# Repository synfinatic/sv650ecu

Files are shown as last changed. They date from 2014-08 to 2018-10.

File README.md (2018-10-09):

## Suzuki SV650 ECU Decoder

This is the Arduino code (for a [PJRC Teensy 2.0](http://www.pjrc.com/store/teensy.html)) 
and necessary CAD/schematic files for creating a PCB to creating your own 
2nd Generation SV650 ECU Decoder to replace the error lights & codes normally 
displayed by the stock dash unit.

This supports the following:

 * Oil pressure warning light
 * Neutral light
 * EFI warning light
 * Low fuel light *
 * Display the water temp from the the stock water temp sensor
 * Ability to decode EFI error codes from the SV650 ECU
 * TPS adjustment indicator **

[*] Note: Untested.

[**] Note: Normally the 4 digit LED display shows the water temp. 
To show the TPS indicator or ECU error codes, you’ll need to use a 
“Suzuki diagnostic tool” (aka a paperclip) to short two wires per the shop manual.

More information about this project is available 
[on my blog](http://synfin.net/sv650ecu "Suzuki SV650 ECU Decoder") and 
[on the wiki](https://github.com/synfinatic/sv650ecu/wiki).

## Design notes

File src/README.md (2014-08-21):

### Code

 * __sv650_reader__ This is the code which runs on the SV650 ECU Decoder and decodes the messages sent by the ECU.
 * __sv650_generator__ This is code written for an Arduino to emulate an SV650 ECU.
 * __sv650_temp__ This is code I wrote to walk through all the ADC temp values generated by the ECU to figure out how to map them to degrees fareinheit.
 * __SWSerial7800__ Customized version of NewSoftSerial library with support for 7800 baud

### Important

In order to build sv650_reader, sv650_generator and sv650_temp for Arduino, you will
need to import the 7800Serial library into the Arduino IDE.  To do so:
 1. Sketch -> Import Library -> Add Library
 2. Select the SWSerial7800 directory
 3. Click the "Choose" button

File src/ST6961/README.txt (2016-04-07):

This is the ST6961 library for the 4 digit LED display used
by sv650_reader, etc.  It's apparently now called the PT6961?

http://gtbtech.com/?p=528

Including it here for posterity sake.  To use it, be sure to
import this library into your Arduino IDE.

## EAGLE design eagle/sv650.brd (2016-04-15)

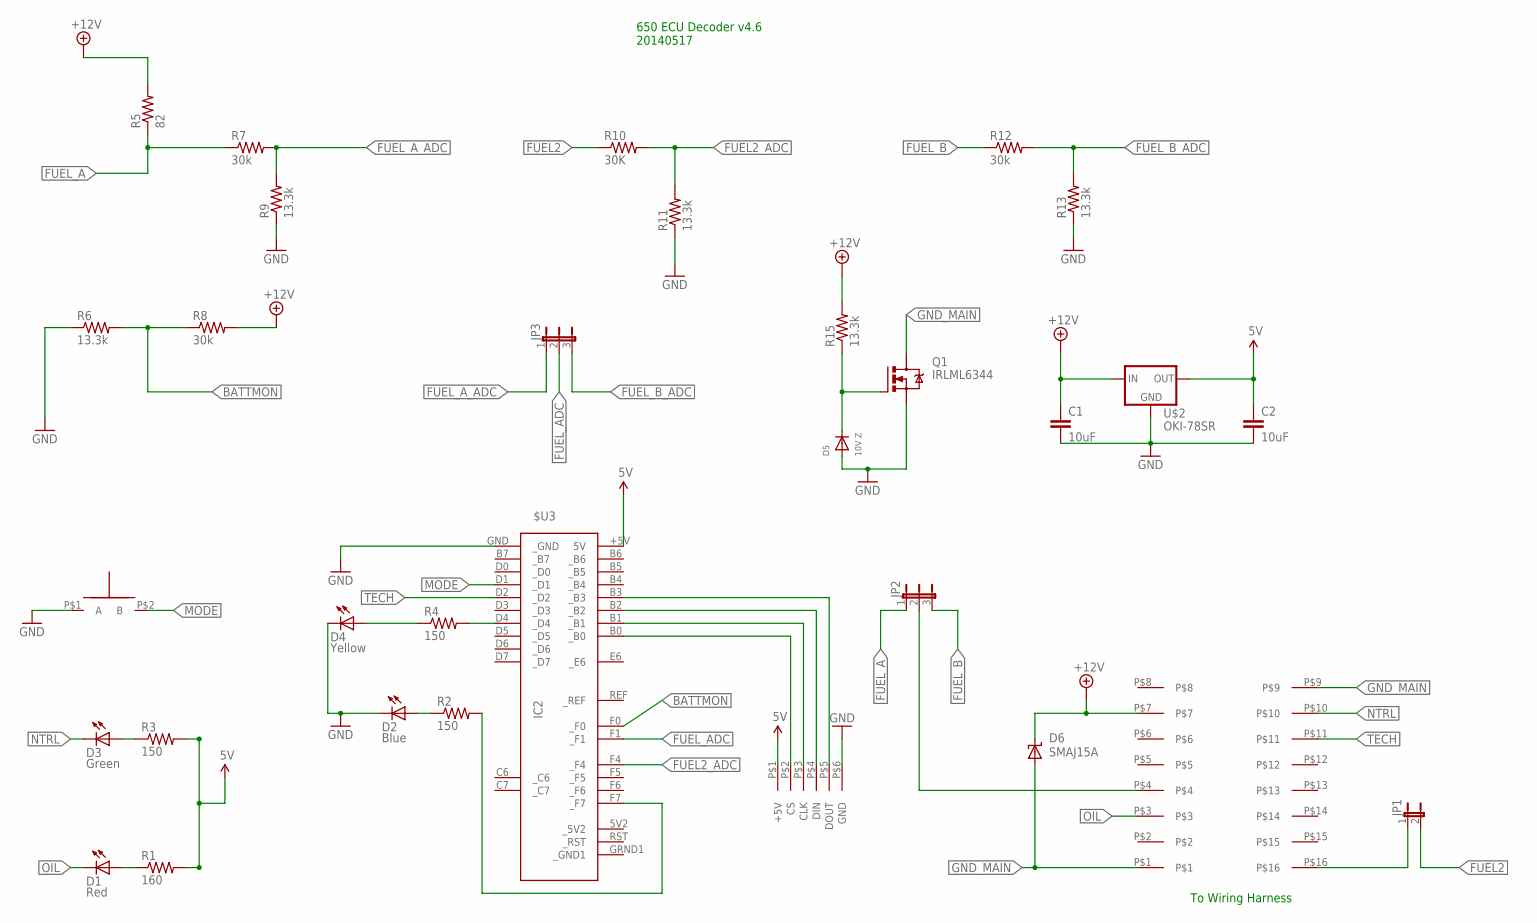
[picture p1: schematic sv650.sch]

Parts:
$U3: IC2; TEENSY
C1, C2: 10uF; C0805
D1: Red; LED10MM
D2: Blue; LED5MM
D3: Green; LED10MM
D4: Yellow; LED10MM
D5: 10V Z; SOD-123
D6: SMAJ15A; SMBG
JP1: JP1E; JP1
JP2, JP3: JP2E; JP2
Q1: IRLML6344; SOT23
R1: 160; M0805; MPN CRCW0805160RFKEA
R2, R3, R4: 150; M0805; MPN MCHP05W4F1500T5E
R5: 82; AXIAL-0.9
R6: 13.3k; M0805; MPN CRCW080510K0FKTA
R7, R12: 30k; M0805
R8: 30k; M0805; MPN CRCW080510K0FKTA
R9, R11, R13, R15: 13.3k; M0805
R10: 30K; M0805
U$1: OASIS-7-SEG-DISPLAY
U$2: OKI-78SR; OKI-78SR-H
U$3: TE-174975-2
U$10: R13-509A-05-BB/R13-509A-05-BR

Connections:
5V: $U3.+5V (5V), C2.1, R1.2, R3.2, U$1.P$1 (+5V), U$2.P$3 (OUT)
+12V: C1.1, D6.C, R5.P$2 (2), R8.2, R15.2, U$2.P$1 (IN), U$3.P$7
BATTMON: $U3.F0 (_F0), R6.2, R8.1
FUEL2: JP1.2, R10.1
FUEL2_ADC: $U3.F4 (_F4), R10.2, R11.2
FUEL_A: JP2.1, R5.P$1 (1), R7.1
FUEL_ADC: $U3.F1 (_F1), JP3.2
FUEL_A_ADC: JP3.1, R7.2, R9.2
FUEL_B: JP2.3, R12.1
FUEL_B_ADC: JP3.3, R12.2, R13.2
GND: $U3.GND (_GND), C1.2, C2.2, D2.K (C), D4.K (C), D5.A, Q1.2 (S), R6.1, R9.1, R11.1, R13.1, U$1.P$6 (GND), U$2.P$2 (GND), U$10.P$1 (A)
GND_MAIN: D6.A, Q1.3 (D), U$3.P$1, U$3.P$9
MODE: $U3.D1 (_D1), U$10.P$2 (B)
unnamed: $U3.B0 (_B0), U$1.P$2 (CS)
unnamed: $U3.B1 (_B1), U$1.P$3 (CLK)
unnamed: $U3.B2 (_B2), U$1.P$4 (DIN)
unnamed: $U3.B3 (_B3), U$1.P$5 (DOUT)
unnamed: D3.A, R3.1
unnamed: D2.A, R2.1
unnamed: D1.A, R1.1
unnamed: $U3.D4 (_D4), R4.2
unnamed: JP2.2, U$3.P$4
unnamed: JP1.1, U$3.P$16
unnamed: $U3.F7 (_F7), R2.2
unnamed: D5.C, Q1.1 (G), R15.1
NTRL: D3.K (C), U$3.P$10
OIL: D1.K (C), U$3.P$3
R2: D4.A, R4.1
TECH: $U3.D2 (_D2), U$3.P$11

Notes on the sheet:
To Wiring Harness
650 ECU Decoder v4.6 20140517

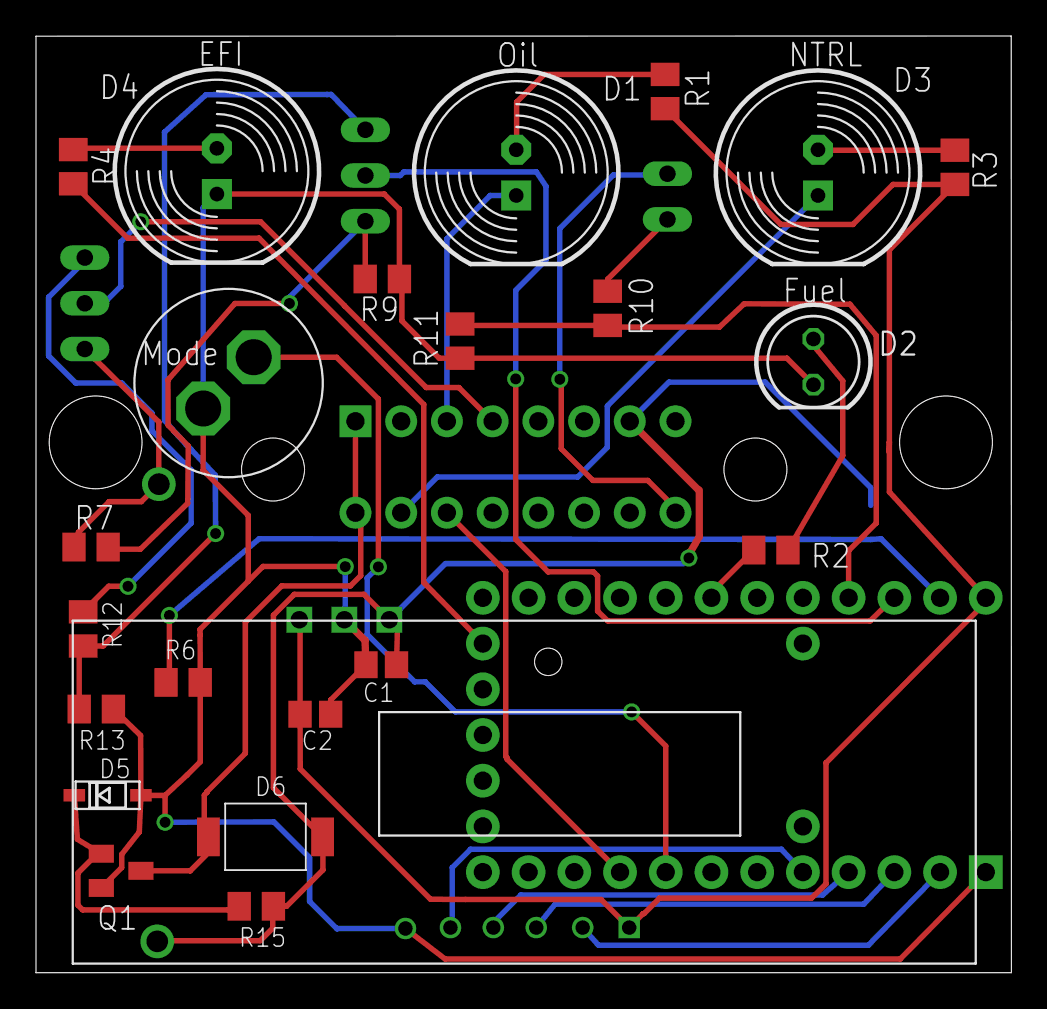
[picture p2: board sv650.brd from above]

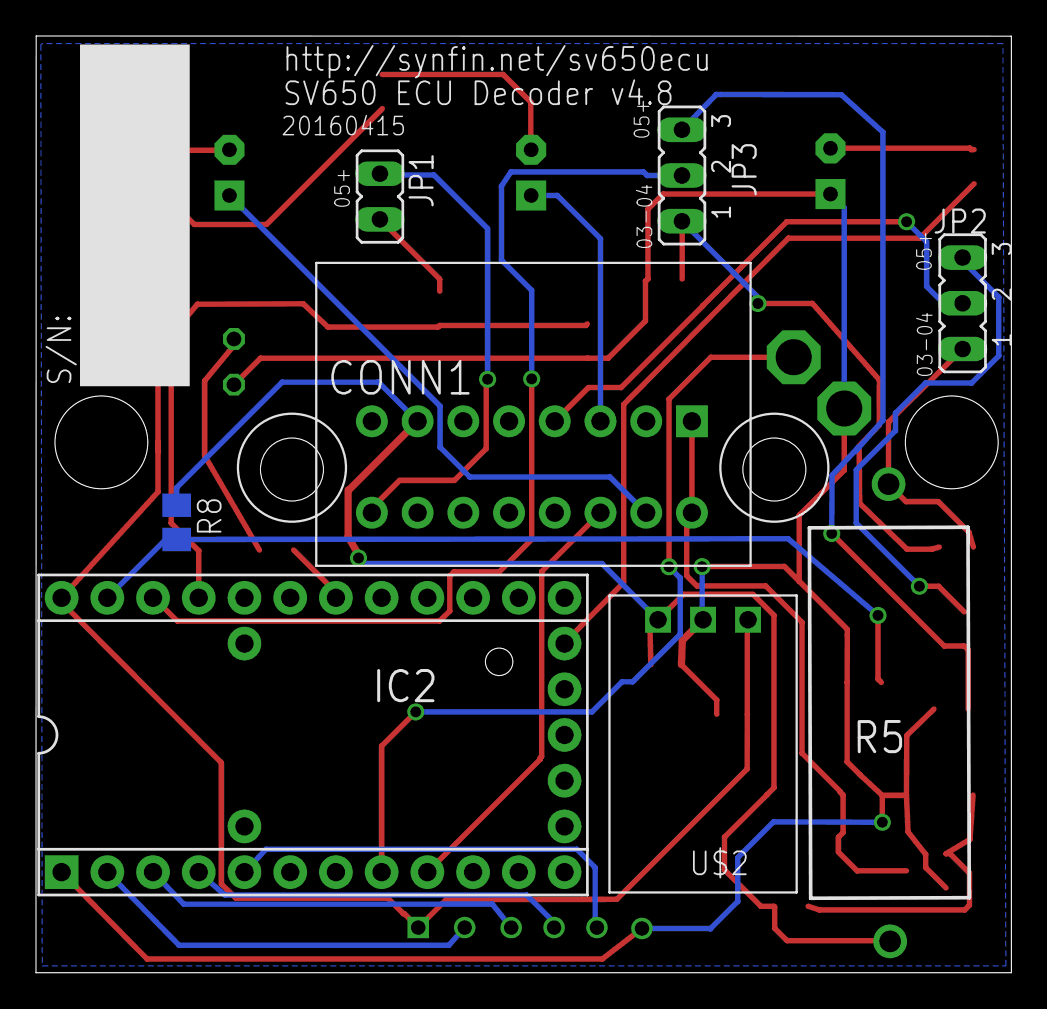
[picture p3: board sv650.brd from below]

Board: 2 copper layers, 54.2 x 52.0 mm, 32 parts (8 on the bottom side), 29 nets.

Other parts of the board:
U$5: STANDOFF

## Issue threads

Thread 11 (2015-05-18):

Add support for tach

synfinatic, 2015-05-18:
Needs to be on D0 (pin 5) for interrupt

synfinatic, 2015-05-18:
Ran out of interrupt pins.  (mode, oil, neutral, serial RX)

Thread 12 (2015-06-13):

Add support for K-line diagnostic

synfinatic, 2015-06-13:
Would be able to get gear position???  K-line is the serial debug port.

http://forum.arduino.cc/index.php?topic=236092.60

synfinatic, 2015-09-24:
http://www.aliexpress.com/item/SDS-For-Suzuki-Motorcycle-Diagnosis-System-Motorcycle-code-scanner/32356452298.html

k-line is also called SDS, and kwp2000.  appears to be a serial protocol
https://en.wikipedia.org/wiki/Keyword_Protocol_2000

synfinatic, 2015-10-06:
I ended up buying one of the Suzuki OBD/SDS diagnostic tools off of eBay for about $55.  Works great.  Looks like I can get air temp, water temp, gear position, rpm, TPS, etc all via the k-line.  You can even get what FI error codes have happened in the past.

To support the k-line, you need something like a ST L9637 to convert it to serial for a micro controller.

synfinatic, 2015-10-06:
ST L9637 spec sheet: [CD00000234.pdf](https://github.com/synfinatic/sv650ecu/files/8805/CD00000234.pdf)

synfinatic, 2015-10-11:
Manual circuit https://drive.google.com/file/d/0B1GutcZzC5ZvTzZsWFVzVWpVZnc/view

synfinatic, 2016-03-07:
Ended up buying an ELM327 based solution to see if that could read/decode the K-line on the SV.  Answer: No.

synfinatic, 2016-05-16:
Good references:
 * https://github.com/HerrRiebmann/KDS2Bluetooth
 * http://ecuhacking.activeboard.com/t56234221/kds-protocol/

synfinatic, 2016-05-18:
So looks like not only is Kawi's KWP2000 different from Suzuki, but we have differences between different models of Suzuki which explains the problem AiM has with my SV, but it working on the GSXR.

pathumha23, 2017-09-05:
Suzuki KWP2000 is different from conventional KWP2000 used in US and Europe systems
Use a scanner that supports JOBD protocol
Suzuki K line 1 and 2 is properitory and it is only communicated via JOBD capable tools
eg - Xtool PS 701JP , OBDMATE OM500

Or use an ELM 327 that supports KWP2000 (ISO 14230) (pin no. 7) and use OBD Driver or OBD Info San Android Apps as they support Suzuki K line 1 and 2

sirapol, 2025-04-07:
Are you still stuck it ?

MeY0u, 2025-07-09:
> Are you still stuck it ?

Got any knowledge about Suzuki marine sds?
Looking into reading df150

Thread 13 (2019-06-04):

Please release consolidated code

NoobDude2001, 2019-06-04:
Hello, I am attemtping to replicate this project. Would you mind posting a .ino file with the code for all the features together? I am new to Arduino and coding, and  I am struggling to get the syntax correct when putting the different features together.

Please and thank you!

Closed 2019-06-07.

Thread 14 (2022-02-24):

Datastream interrupt

gsmith1979, 2022-02-24:
HI there Aaron,
Sorry not sure if this is something you have looked at in the last 7 years, but I am trying this out on a Gen2 Hayabusa (08-20) dash cluster, ultimately I am working to take a CAN input into a CANBED and then produce the data serial stream out to the dash.

Using your or some sketches similar I am able to talk with the hayabusa dash no problem and have been able to operate the coolant gauge, FI codes, ABC power mode indication, and the gear indicator.  This all works wonderfully if I hard code set values and say things like temp = 100, or set the gear bits etc.  The moment I bring a CAN message in and make dash items based on it, or even an analogRead command, or even try make the temperature change on it's own by every 5 or 10 seconds have it multiply by a random number so it changes, the serial stream seems to get interrupted somehow.

I have verified the gen2 hayabusa has 7800 baud rate, I have made some adjustments to the message spacing to line up with what I have observed with my scope, but I am stumped and can't seem to get the dash to consistently respond to changes coming from any external source.

Wondering if this is anything that you have encountered before in your journeys?  I am not a programmer at all, my understanding is pretty limited, but seems like maybe I am missing something to make it work correctly.

I made a quick video last night for a buddy trying to help me out with the project if you were interested to take a look at what is happening.  Thanks very much for the code you have posted and time spent on this!.
https://www.youtube.com/watch?v=ZMGqHi9cjfo

Greg

gsmith1979, 2022-02-24:
A couple of my terrible hacky sketches attached if you were interested.

[receive_TPS_new_with_Serial_works.zip](https://github.com/synfinatic/sv650ecu/files/8135562/receive_TPS_new_with_Serial_works.zip)

synfinatic, 2022-02-25:
So semi-educated and random guess:  It sounds like a timing issue.  The dash is expecting 7800 baud rate.  So if your code is busy and it "misses" writing a message, it would now be writing messages at an offset.  Pretend each "message" is 4 bytes (I honestly forget how long it is an too lazy too look it up) the dash would expect 5 messages like this sent over the wire:

```
1111222233334444555
```

But if your script is busy during the 3rd message since it is updating and it "misses" your script might send:

```
1111222233_334444555
```

that gap means the bytes are corrupted for messages 3, 4 and 5 because the first byte of message 4 you send is interpreted as the 2nd byte of message 4 and so on.

Anyways, that's my semi-educated guess at 8pm with a glass of wine sitting on my desk. :)   Good luck!

gsmith1979, 2022-02-25:
Not sure what was going on in the original sketch, but I used your temp output sketch as a starting point and was able to add CAN code to it and get can messages in properly controlling the dash with out any issues, so much appreciation for your sketches posted!  Thank you Aaron!

Closed 2022-02-26.

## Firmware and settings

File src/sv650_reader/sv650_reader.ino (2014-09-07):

/* 
 * Copyright 2014 (c) Aaron Turner
 * This code is released under the GPLv3 license.  Please see the LICENSE file 
 * for details.
 *
 * More information is available here: https://github.com/synfinatic/sv650ecu
 *
 * Suzuki SV650 2nd gen (03-06) ECU -> Dash protocol decoder
 * Black/Green wire from ECU to Dash.  Simple serial protocol
 * running at 7800 BAUD.  Each message is 8 bytes.  10 messages/sec
 * 10ms gap between bytes, 30ms gap between messages
 *
 * This code is written for a PJRC Teensy 2.0
 */


#include <ctype.h>
#include <stdarg.h>
#include <ST6961.h>
#include <MsTimer2.h>
#include <avr/pgmspace.h>

#include "sv650_reader.h"
#include "display.h"
#include "print.h"
#include "utils.h"

// pre-declare our functions
void mode_button_interrupt();
void print_led_display();
void select_next_mode();
void flash_update();
void flash_fast_update();
void no_flash_update();

/****************************************************************************
 * globals
 ****************************************************************************/

// pins we don't use on the Teensy board
static char used_pins[] = { 
    EFI_WARN, CS, CLK, MOSI, MODE_PIN, RX, TX, BATT_MON_DIGITAL, 
    FUEL_DIGITAL, FUEL2_DIGITAL
};

// Order of 4-LED display modes
static const mode mode_list[] = {
#ifdef ENABLE_TEMP
    MODE_TEMP,
#endif
#ifdef ENABLE_BATT
    MODE_BATTERY,
#endif
    MODE_EFI_ERROR,
    MODE_BAD_ECU,
    MODE_LAST
};

byte sbytes[8];              // storage for our messages from the ECU
unsigned int last_efi_light = 0;
bool efi_alarm = false;       // true or false if we've seen an error code
bool bad_ecu   = false;         // true or false if we have EFI communication issues
bool low_batt  = false;        // true or false for low voltage
bool bad_temp  = false;        // true or flase for water temp too high
#ifdef ENABLE_TEMP
mode current_mode = MODE_TEMP;
#elif defined ENABLE_TEMP
mode current_mode = MODE_BATTERY;  // current 4-LED display mode
#else
mode current_mode = MODE_CLEAR;
#endif
volatile bool mode_button_pressed = false;
char tps_adjust;
int efi_error_code = -1;
bool valid_message = false;

// Init our hardware serial & LCD display
HardwareSerial ecu = HardwareSerial();
ST6961 led = ST6961(MOSI, CLK, CS);

/****************************************************************************
 * main setup 
 ****************************************************************************/
void 
setup() {
    int i;
    unsigned int j;
    bool pin_is_used;

    // Put unused pins in output mode so they don't float
    for (i = 0; i <= 24;  i++) {
        pin_is_used = false;
        for (j = 0; j < sizeof(used_pins); j++) {
            if (i == used_pins[j]) {
                pin_is_used = true;
                break;
            }
        }
        if (! pin_is_used) {
#ifdef DEBUG_TABLES
            serial_printf("Marking pin #%d as OUTPUT\n", i);
#endif
            pinMode(i, OUTPUT);
        }
    } 

    // initialize serial communication to the ECU
    Serial.begin(SERIAL_SPEED);
    Serial.println("begin setup()");
    ecu.begin(ECU_SPEED);

    // Make sure BATT_MON pin is INPUT or we'll fry the board
    pinMode(BATT_MON, INPUT);
    
    // attach interrupt handler for the mode button
    pinMode(MODE_PIN, INPUT_PULLUP);
    attachInterrupt(MODE_INT, mode_button_interrupt, FALLING);

    // we control the EFI warning LED
    pinMode(EFI_WARN, OUTPUT);

    // initalize the LED display
    led.initDisplay();

    // clear display
    display_chars(' ', ' ', ' ', ' ');

    // clear sbytes[]
    clear_buf();
   
#ifdef DEBUG_TABLES 
    /*
     *  Prints out all our static tables to serial for debugging/info purposes
     */ 
    i = 0;
    serial_printf("our tps_table[] size is %u bytes\n", sizeof(tps_table));
    while (tps_table[i].bindex != 0xff) {
        serial_printf("tps_table[%d].bindex = '%02x'\n", i, tps_table[i].bindex);
        serial_printf("tps_table[%d].mask   = '%02x'\n", i, tps_table[i].mask);
        serial_printf("tps_table[%d].error  = '%s'\n", i, tps_table[i].error);
        i++;
    }

    serial_printf("our error_table[] size is %u bytes\n", sizeof(error_table));
    while (error_table[i].bindex != 0xff) {
        serial_printf("error_table[%d].bindex = '%02x'\n", i, error_table[i].bindex);
        serial_printf("error_table[%d].mask   = '%02x'\n", i, error_table[i].mask);
        serial_printf("error_table[%d].error  = '%s'\n", i, error_table[i].error);
        i++;
    }

    serial_printf("%s", "our display_table[]:\n");
    for (i = 0; i <= 127; i++) {
        serial_printf("%c = %c\n", i, pgm_read_byte_near(display_table +  i));
    }
#endif 

    digitalWrite(EFI_WARN, LOW);
    MsTimer2::start();
    MsTimer2::set(TIMER_MS, no_flash_update);

    Serial.println("READY!");
}

/****************************************************************************
 * main loop 
 ****************************************************************************/
void 
loop() {
    static unsigned long ms_last = 0;     // last time we saw a message
    unsigned long delta, now, parse_delta;
    static bool efi_alarm_light_on = false;
    static bool temp_alarm_light_on = false;
    static unsigned long last_parse = 0;
    byte data;
    int count, i, valid;

    now = millis();
    delta = now - ms_last;
    parse_delta = now - last_parse;


    count = ecu.available();
    for (i = 0; i < count; i++) {
        // data is available to be read from the ECU
        data = (byte)ecu.read();
        ms_last = now;

        /*
         * Figure out if we got a complete & valid message
         */
        valid = parse_ecu_byte(data, delta);
        if (valid == 0) {
            valid_message = false;
        } else if (valid == 1) {
            valid_message = true;
        }

        // only parse valid messages every DECODE_MS 
        if ((valid != -1) && valid_message && (parse_delta >= DECODE_MS)) {
            parse_message();
            last_parse = now;
            print_led_display();
        }

        /*
         * Figure out which *_update() function to call via MsTimer2
         */
        if (bad_ecu) {
            // Turn off the EFI light if necessary
            dbg_serial_printf("ecu comms restored! Turning off light.\n");
            bad_ecu = false;
            MsTimer2::set(TIMER_MS, no_flash_update);
            digitalWrite(EFI_WARN, LOW);
        } else if (bad_temp && ! temp_alarm_light_on) {
            // Temperature is too high, flash the light fast
            dbg_serial_printf("bad temp.  Flashing fast.\n");
            temp_alarm_light_on = true;
            MsTimer2::set(TIMER_MS, flash_fast_update);
        } else if (efi_alarm && ! efi_alarm_light_on) {
            // We have an EFI error, so solid EFI light
            dbg_serial_printf("efi alarm, solid light.\n");
            efi_alarm_light_on = true;
            MsTimer2::set(TIMER_MS, no_flash_update);
            digitalWrite(EFI_WARN, HIGH);
        }  else if (! efi_alarm && efi_alarm_light_on) {
            // No longer have EFI error, so turn off the EFI light
            dbg_serial_printf("efi alarms disabled.  Turning off light.\n");
            efi_alarm_light_on = false;
            MsTimer2::set(TIMER_MS, no_flash_update);
            digitalWrite(EFI_WARN, LOW);
        } else if (! bad_temp && temp_alarm_light_on) {
            // Temperature is low again, stop flashing
            dbg_serial_printf("temp is now ok.  Turning off light.\n");
            temp_alarm_light_on = false;
            MsTimer2::set(TIMER_MS, no_flash_update);
            digitalWrite(EFI_WARN, LOW);
        }
    } 
    if (! count) {
        // Check to see if ECU is not available
        if ((delta > NO_ECU_WARN_DELAY) && ! bad_ecu) {
            dbg_serial_printf("bad ecu comms.  Flashing slowly.\n");
            bad_ecu = true;
            MsTimer2::set(TIMER_MS, flash_update);

            // Clear any EFI alarm errors
            efi_alarm = false;
        }
    }

    // always update the display if user pressed the mode button
    if (mode_button_pressed) {
        print_led_display();
    }
}

/*
 * Just update the LED display
 */
void
no_flash_update() {
    if (! valid_message) {
        print_led_display();
    }
}

/*
 * Flash the EFI error really fast for bad temperature
 * and update the LED display
 */
void 
flash_fast_update() {
    static boolean hilo = 0;
    static unsigned long blink_time = 0;
    unsigned long now;

    now = millis();
    if (blink_time == 0) {
        blink_time = now + (BLINK_MS/4);
    }

    if (now > blink_time) {
        blink_time = now + (BLINK_MS/4);
        digitalWrite(EFI_WARN, hilo);
        hilo = !hilo;
    }

    if (! valid_message) {
        print_led_display();
    }

}

/*
 * Flash EFI error light & update the LED display
 */
void 
flash_update() {
    static boolean hilo = 0;
    static unsigned long blink_time = 0;
    unsigned long now;

    now = millis();
    if (blink_time == 0) {
        blink_time = now + BLINK_MS;
    }

    if (now > blink_time) {
        blink_time = now + BLINK_MS;
        digitalWrite(EFI_WARN, hilo);
        hilo = !hilo;
    }
    
    if (! valid_message) {
        print_led_display();
    }
}


/*
 * Figures out what mode the display should be after each button press
 */
void
mode_button_interrupt()
{
    static unsigned long last_time = 0;
    unsigned long now;

    now = millis();
    if ((last_time + DEBOUNCE_MS) < now) {
        mode_button_pressed = true;
        last_time = now;
    }
}

/*
 * Based on our current display mode, figure out what the next
 * valid mode is
 */
void
select_next_mode()
{
    bool again = true;
    int max_times = 0;
    static unsigned int mode_index = MODE_LAST;

    dbg_serial_printf("select_next_mode(): Current mode: %u\t\t", current_mode);

    max_times = MODE_CLEAR * 2;

    while (again && max_times) {
        if (mode_index >= MODE_LAST) {
            mode_index = 0;
        } else {
            mode_index += 1;
        }
        current_mode = mode_list[mode_index];

        // See if we need to look for the next mode
        again = false;
        if (((current_mode == MODE_BAD_ECU) && ! bad_ecu) ||
            ((current_mode == MODE_EFI_ERROR) && ! efi_alarm)) {
            again = true;
        }
        max_times -= 1;
    }
    if (again && ! max_times) {
        current_mode = MODE_CLEAR;
    }
    dbg_serial_printf("New mode: %u\n", current_mode);
}


void
clear_efi_light(unsigned int code)
{
    if ((last_efi_light & code) == code) {
        last_efi_light -= code;
    }
}

void
set_efi_light(int code)
{
    if ((last_efi_light & code) == 0) {
        last_efi_light += code;
    }
}

/*
 *  Figures out what to display on the 4-LED
 */
void
print_led_display()
{
    static mode last_mode = MODE_LAST;

    /*
     * If a new bad condition (EFI error, no EFI communication or low battery)
     * then switch to that display mode.  Order of the if/else sets the priority.
     */
    if (mode_button_pressed) {
        mode_button_pressed = false;
        dbg_serial_printf("Mode button pressed\n");
        select_next_mode();
    } else if (((last_efi_light & EFI_LIGHT_BAD_ECU) == 0) && bad_ecu) {
        // bad efi enabled
        current_mode = MODE_BAD_ECU;
        set_efi_light(EFI_LIGHT_BAD_ECU);
    } else if (((last_efi_light & EFI_LIGHT_ALARM) == 0) && efi_alarm) {
        // efi error enabled
        current_mode = MODE_EFI_ERROR;
        set_efi_light(EFI_LIGHT_ALARM);
#ifdef ENABLE_BATT
    } else if (((last_efi_light & EFI_LIGHT_LOW_BATT) == 0) && low_batt) {
        // low battery enabled
        current_mode = MODE_BATTERY;
        set_efi_light(EFI_LIGHT_LOW_BATT);
#endif
    } else if (((last_efi_light & EFI_LIGHT_BAD_ECU) == EFI_LIGHT_BAD_ECU) && ! bad_ecu) {
        // clear bad efi alarm
        clear_efi_light(EFI_LIGHT_BAD_ECU);
        if (current_mode == MODE_BAD_ECU) {
            current_mode = MODE_LAST;
            select_next_mode();
        }
    } else if (((last_efi_light & EFI_LIGHT_ALARM) == EFI_LIGHT_ALARM) && ! efi_alarm) {
        // clear efi alarm
        clear_efi_light(EFI_LIGHT_ALARM);
        if (current_mode == MODE_EFI_ERROR) {
            current_mode = MODE_LAST;
            select_next_mode();
        }
#ifdef ENABLE_BATT
    } else if (((last_efi_light & EFI_LIGHT_LOW_BATT) == EFI_LIGHT_LOW_BATT) && ! low_batt) {
        // clear low battery warning
        clear_efi_light(EFI_LIGHT_LOW_BATT);
        if (current_mode == MODE_BATTERY) {
            current_mode = MODE_LAST;
            select_next_mode();
        }
#endif
    }

#ifdef DEBUG
    if (current_mode != last_mode) {
        serial_printf("display mode changing! %d -> %d\n", last_mode, current_mode);
    }
#endif

    switch (current_mode) {
        case MODE_BAD_ECU:
            print_led_bad_ecu();
            break;
        case MODE_EFI_ERROR:
            dbg_serial_printf("Updating EFI error message 0x%04x\n", efi_error_code);
            print_led_error(tps_adjust, efi_error_code, efi_alarm);
            break;
#ifdef ENABLE_BATT
        case MODE_BATTERY:
            print_battery_voltage();
            break;
#endif
#ifdef ENABLE_TEMP
        case MODE_TEMP:
            if (print_led_temp() >= TEMP_WARN) {
                bad_temp = true;
            }
            break;
#endif
        default:
            serial_printf("Invalid current_mode %u.  Won't print anything\n",
                    (unsigned int)current_mode);
            select_next_mode();
    }
    last_mode = current_mode;
}

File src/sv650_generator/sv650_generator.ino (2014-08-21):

/* 
 * Copyright 2013 Aaron Turner
 *
 * Arduino Uno based SV650 ECU TACH line emulator.  I wrote this to 
 * make it easier to test my sv650 decoder code.  
 *
 */

// #define USE_TEENSY  // Define if using Teensy instead of Arduino Uno

#ifndef USE_TEENSY
#include <SWSerial7800.h>
#endif

#include <ST6961.h>
#define CS 10
#define MOSI 11
#define CLK 13

#define RX 7
#define TX 8                // ECU pin  
#define BUTTON 2
#define INTERRUPT 0         // INT for pin 2

#define ECU_SPEED 7800
#define SERIAL_SPEED 9600
#define BLINK_LED 13 
#define BLINK_MS 500
#define DEBOUNCE_MS 1000

volatile bool change_ecu_code = 0;


#ifndef USE_TEENSY
// init SWSerial7800 for ECU communications.  Need to keep ecu global
SWSerial7800 ecu(RX, TX);
#else
HardwareSerial ecu = HardwareSerial();
#endif
ST6961 LED(MOSI, CLK, CS);


/*
 *  Error codes to rotate through
 */
typedef struct _ECU_CODES {
    byte bytes[8];
} ECU_CODES;

static ECU_CODES ecu_codes_table[] =
{
    { 0x5a , 0x0  , 0x0  , 0    , 0    , 0    , 0    , 0 }    ,  // 100F
    { 0x1c , 0xc0 , 0x0  , 0    , 0    , 0    , 0    , 0 }    ,  // 184F
    { 0x10 , 0xc0 , 0x0  , 0    , 0    , 0    , 0    , 0 }    ,  // 227F
    { 0x2c , 0xc8 , 0x0  , 0    , 0x40 , 0    , 0    , 0 }    ,  // 227F, C29
    { 0x0a , 0x08 , 0x80 , 0    , 0    , 0    , 0    , 0 }    ,  // HI F, C41
    { 0x2c , 0xc8 , 0x80 , 0    , 0xa0 , 0    , 0    , 0 }    ,  // 153F, C28, C41, C49
    { 0xff , 0xff , 0xff , 0xff , 0xff , 0xff , 0xff , 0xff }
};


// printf to the HW serial port
void 
serial_printf(char *fmt, ... ) {
    char tmp[128]; // resulting string limited to 128 chars
    va_list args;
    va_start (args, fmt );
    vsnprintf(tmp, 128, fmt, args);
    va_end (args);
    Serial.print(tmp);
}

/*
 * Calculate the checksum
 */
byte
gen_csum(unsigned int code) {
    byte check_sum = 0;

    // Calculate check sum byte  
    for (int x = 0; x <= 6; x++) {
        check_sum = check_sum + ecu_codes_table[code].bytes[x];
    }

    check_sum = 256 - check_sum;

    return check_sum;
}

void
button_interrupt(void)
{
    static unsigned long last_time = 0;
    unsigned long now;

    now = millis();
    if ((last_time + DEBOUNCE_MS) < now) {
        change_ecu_code = 1;
        last_time = now;
    }
}



/*
 *  Initialize everything
 */
void 
setup() {
    unsigned int i = 0;
    ecu.begin(ECU_SPEED);
    Serial.begin(SERIAL_SPEED);
    pinMode(BUTTON, INPUT_PULLUP);
    attachInterrupt(INTERRUPT, button_interrupt, FALLING);


    // calc checksums for all the messages
    while (ecu_codes_table[i].bytes[0] != 0xff) {
        ecu_codes_table[i].bytes[7] = gen_csum(i);
        i++;
    }
    serial_printf("Sending: %02x %02x %02x %02x %02x %02x %02x %02x\n", 
        ecu_codes_table[0].bytes[0], 
        ecu_codes_table[0].bytes[1], 
        ecu_codes_table[0].bytes[2], 
        ecu_codes_table[0].bytes[3], 
        ecu_codes_table[0].bytes[4], 
        ecu_codes_table[0].bytes[5], 
        ecu_codes_table[0].bytes[6], 
        ecu_codes_table[0].bytes[7]);
}
/*
 *  Blink our status light
 */
void 
blink() {
    static int hilo = 0;
    static unsigned long last = millis();

    if (millis() - last >= BLINK_MS) {
        hilo = ! hilo;
        digitalWrite(BLINK_LED, hilo);
        last = millis();
    }
}

void 
loop() {
    int x;
    static unsigned int ecu_code = 0;

    if (change_ecu_code) {
        serial_printf("%s", "button pressed!\n");
        change_ecu_code = 0;
        if (ecu_codes_table[ecu_code+1].bytes[0] == 0xff) {
            ecu_code = 0;
        } else {
            ecu_code ++;
        }
        serial_printf("Sending: %02x %02x %02x %02x %02x %02x %02x %02x\n", 
            ecu_codes_table[ecu_code].bytes[0], 
            ecu_codes_table[ecu_code].bytes[1], 
            ecu_codes_table[ecu_code].bytes[2], 
            ecu_codes_table[ecu_code].bytes[3], 
            ecu_codes_table[ecu_code].bytes[4], 
            ecu_codes_table[ecu_code].bytes[5], 
            ecu_codes_table[ecu_code].bytes[6], 
            ecu_codes_table[ecu_code].bytes[7]);
    }

    // Write data bytes to serial
    for (x = 0; x <= 7; x++) {
        ecu.write(ecu_codes_table[ecu_code].bytes[x]);
        delay(10);
    }

    // Intermessage delay
    delay(20);  // only use 20ms because we already slept 10ms earlier
    blink();
}

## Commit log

2013-09-09 Initial checkin of Teensy 2.0 code and Diptrace files necessary for creating a PCB
2013-09-09 add Eagle files which are a work in progress!
    [sv650.brd, sv650.sch]
2013-09-10 add two Arduino tools I used to help develop the code in sv650_reader Neither are particularly pretty/clean, but they are good starting points for creating your own ECU emulator for other Suzuki seri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
2013-09-10 improve board layout and update resistor divider circuit
    [sv650.brd, sv650.sch]
2013-09-11 add .gitignore Update schema and board with updated connector, resistors for voltage divider and zener.
    [sv650.brd, sv650.sch]
2013-09-12 ignore all gerber/drill files
2013-09-12 update layout of 7805 to use a pad for solder not drill hole for hard mounting. Update silkscreen and improve layout for sending to OshPark for fabrication.
    Just waiting on feedback on voltage divider & zener.
    [sv650.brd, sv650.sch]
2013-09-14 board as ordered from OshPark for v4.0
    [sv650.brd, sv650.sch]
2013-11-29 document what each Arduino project is for
2013-12-14 Move fuel LED down to have bigger gap to neutral light rev board to 4.1 add date code to board top silk
    [sv650.brd]
2013-12-27 Fix "LO F" message on LED display Fix bad LED error code due to error == -1 Update copyright to 2014 in preperation for the new year
    [display.ino, sv650_reader.h, sv650_reader.ino]
2013-12-30 update board & schema to v4.1 - Add 5V zener to protect ADC from shorts - Add .1uF cap to even out ADC line from noise - Tweak placement of low fuel LED - Tweak placement of S/N: XXXXXX
    [sv650.brd, sv650.sch]
2013-12-30 fix S/N: XXXXX so it is not hidden by the wiring harness connector
    [sv650.brd]
2013-12-31 modify the position of parts & traces to be a little cleaner move LED's away from the top edge of the board
    [sv650.brd]
2013-12-31 remove 20V zener replace 5V zener with 4.7V zener (hard to find 5V zeners) merge 10K + 22K into a single 30K resistor clean up traces & remove lots of vias
    [sv650.brd, sv650.sch]
2014-01-16 Add 'mode' button Add means to detect Very Low Fuel on later models Move +12V back to ignition
    [sv650.brd, sv650.sch]
2014-01-16 Add code to measure & display battery/charge voltage Fix bug with display characters Add support for controlling the colon on the LED display
    [display.ino, sv650_reader.h, sv650_reader.ino]
2014-03-10 put BATT_MON (A0) pin into input mode so we can read the battery voltage
    Also prevents feedback loop which will end up damaging the Arduino
    and overheat the LM7805.
    [sv650_reader.ino]
2014-03-10 Update to v4.2. - Move via away from LM7805 to prevent shorting - Increase size of S/N space
    [sv650.brd, sv650.sch]
2014-03-10 update to show v4.2 and date
    [sv650.sch]
2014-03-10 add comment about setting BATT_MON pin to INPUT
2014-03-11 update temp every second pick a ZENER_DROP_VOLTAGE which works well for both USB and bike battery
2014-03-11 change mode button to pin D1/6 so we can assign an interrupt to it
    [sv650.brd, sv650.sch]
2014-04-22 update code to use correct pins and dynamically put unused pins in OUTPUT
    [sv650_reader.h, sv650_reader.ino]
2014-04-22 - update board to v4.2 with LM7805 w/ heat sink - fix mode button to use a pin supporting interrupts - remove external pullup resistors
    [sv650.brd, sv650.sch]
2014-04-22 update board to v4.3 - switch to LM2674-5.0 - Fix 20V schottky diode
    [sv650.brd, sv650.sch]
2014-04-22 Enable DL1000 error codes
    [sv650_reader.h]
2014-04-27 Fuel level LED is now controlled by Teensy Use LT082CP to measure fuel sensor add 5W 82ohm resistor to fuel line Remove Fuel2 jumper/support
    [sv650.brd, sv650.sch]
2014-05-19 Replace LM7805 with new Murata 5V switching module Move EFI from D6 to D4 to avoid interrupt conflict Add ground plane Add N channel MOSFET for reverse battery protection Remove 5.1V zener from batte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
    [sv650.brd, sv650.sch]
2014-05-19 replace 16V zener with 15V TVS
    [sv650.brd, sv650.sch]
2014-05-19 update to v4.6 move jumpers to back side of board
    [sv650.brd, sv650.sch]
2014-05-19 move jumper silk mask descriptions to bsilk
    [sv650.brd]
2014-05-19 reroute some traces to be cleaner ordered v4.6 via oshpark
    [sv650.brd]
2014-08-04 update code to support v4.2 board design
2014-08-09 Fix water temp EFI alarm light
    [display.ino, sv650_reader.h, sv650_reader.ino]
2014-08-21 New firmware for 4.6 board support
    - Adds support for the mode button to cycle modes
    - Adds support for volts
    - Adds support for water temp
    - EFI is
    - solid for EFI error
    - slow flash bad ECU comms
    - fast flash for water temp too high
    - Includes our own SWSerial7800 library which is just AltSoftSerial
    but with 7800 baud support so people don't have to modify their own
    library for Arduino UNO boards
    - Add dbg_serial_printf() for cleaner code & debugging
    TODO:
    - Need to make sure voltage calculation is accurate
    - Add Low Fuel light support
    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
    [SWSerial7800.cpp, display.ino, print.ino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]
2014-09-07 switch D5 to a SOD-123 package
    [sv650.brd, sv650.sch]
2014-09-07 Fix battery monitor
    used_pins[] were being put in OUTPUT mode, rather then the opposite.
    [sv650_reader.h, sv650_reader.ino]
2015-01-10 update readme to reflect v4.6 board
2016-04-07 Update SV650 Reader to build cleanly under Arduino IDE 1.6.7
    Builds without errors, but I haven't tested the code yet. YMMV!
    [display.ino, sv650_reader.h, utils.ino]
2016-04-15 Work on v4.8 board
    - Updates power module footprint to make pads bigger so the pins fit
    - Other small tweaks based on feedback??
    [sv650.brd, sv650.sch]

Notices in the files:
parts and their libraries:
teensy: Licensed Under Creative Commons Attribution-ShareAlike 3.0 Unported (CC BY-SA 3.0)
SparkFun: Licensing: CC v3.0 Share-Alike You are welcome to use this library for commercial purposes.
